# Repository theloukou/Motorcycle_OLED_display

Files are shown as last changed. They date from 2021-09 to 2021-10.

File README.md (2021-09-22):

# Motorcycle information display
ESP32-based Motorcycle Information Display

This is an ESP32 based system, intented for older motorcycles. It is an expansion of the AVR implementation found in the main_avr branch.
It utilizes a small 128x32 OLED diplay module to display motor and ambient temperatures from a set of NTC thermistor/DS18B20, as well as time information through an RTC IC.

New features compared to the Arduino/AVR version are:
* Syncing RTC time via onboard web server
* Uploading new firmware via Wifi, without need to remove system/connect to PC
* Custom PCB to minimize system footprint. Choice between pin-compatible DS1307/PCF8523

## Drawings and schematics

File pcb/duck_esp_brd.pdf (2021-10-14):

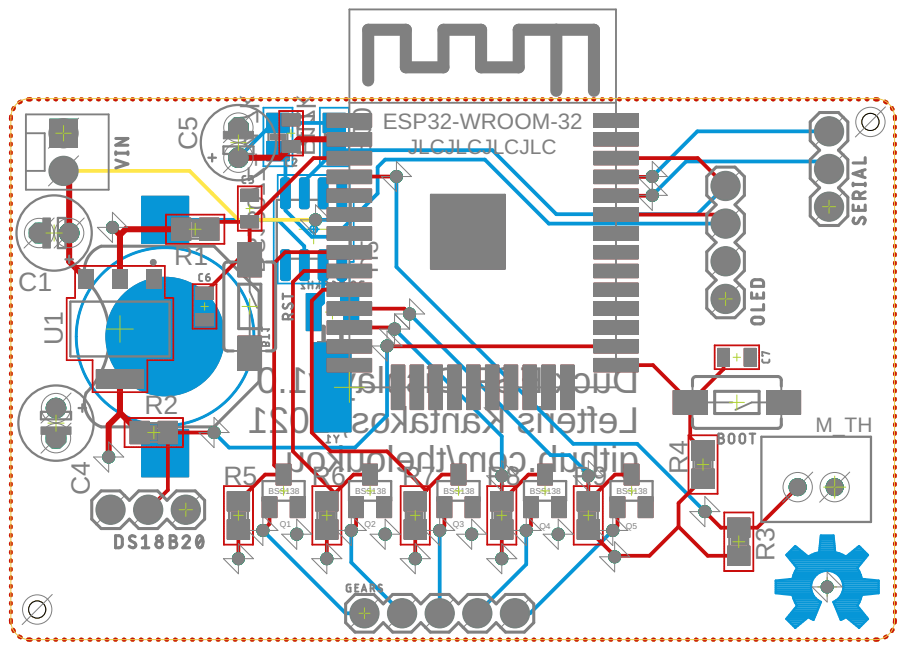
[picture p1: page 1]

DS1307Z+ 4.7k 4.7k 0. 1v yal psi D PSEkcu D 1202, sokat naKsir etf eL uokuol eht/ moc. buhti g U2 R10 R11ESP32-WROOM-32 JLCJLCJLCJLC M_TH R1 R2 R3 U1 R4 C1 C4 C5 Q1 R5 Q2 R6 Q3 R7 Q4 R8 Q5 R9 BSS138 BSS138 BSS138 BSS138 BSS138

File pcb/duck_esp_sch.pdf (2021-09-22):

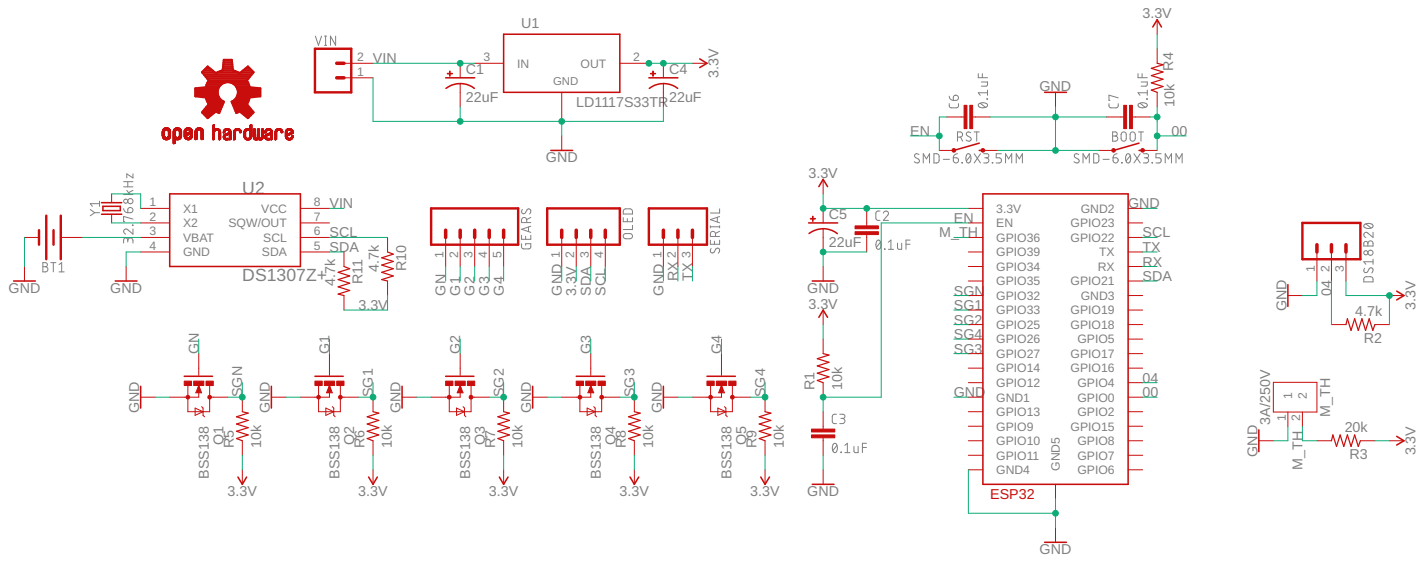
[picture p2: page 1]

10k GND GND 3.3V 3.3V GND GNDLD1117S33TR 3.3V GND G4.7k ND 3.3V 20k GND 3.3V 10k 3.3V 22uF 22uF 22uF BSS138 GND 10k 3.3V BSS138 GND 10k 3.3V BSS138 GND 10k 3.3V BSS138 GND 10k 3.3V BSS138 GND 10k 3.3V DS1307Z+ GND GND 4.7k 4.7k GND4 GPIO11 GPIO10 GPIO9 GPIO13 GND1 GPIO12 GPIO14 GPIO27 GPIO26 GPIO25 GPIO33 GPIO32 GPIO35 GPIO34 GPIO39 GPIO36 EN3.3V GPIO6 GPIO7 GPIO8 GPIO15 GPIO2 GPIO0 GPIO4 GPIO16 GPIO17 GPIO5 GPIO18 GPIO19 GND3 GPIO21 RXTX GPIO22 GPIO23 GND2 GND5 R1 IN 3 OUT 2 GND U1 1234123 123 R2 R3 1 1 2 2M_TH 3A/250V 12 12345 R4 C1 C4 C5 Q1 R5Q2 R6Q3 R7Q4 R8Q5 R9 X1 1 X2 2 VBAT 3 GND 4 SDA 5 SCL 6 SQW/OUT 7 VCC 8 U2 R10 R11 3.3V 3.3V GND GND GND GND SDASDA SDA SCL SCL SCL 00 00 RX RX TX TX M_TH M_TH GN GN G1 G1 G2 G2 G3 G3 G4 G4 EN EN 04 04 VIN VIN SG1 SG1 SG2 SG2 SGN SGN SG4 SG4 SG3 SG3 ESP32

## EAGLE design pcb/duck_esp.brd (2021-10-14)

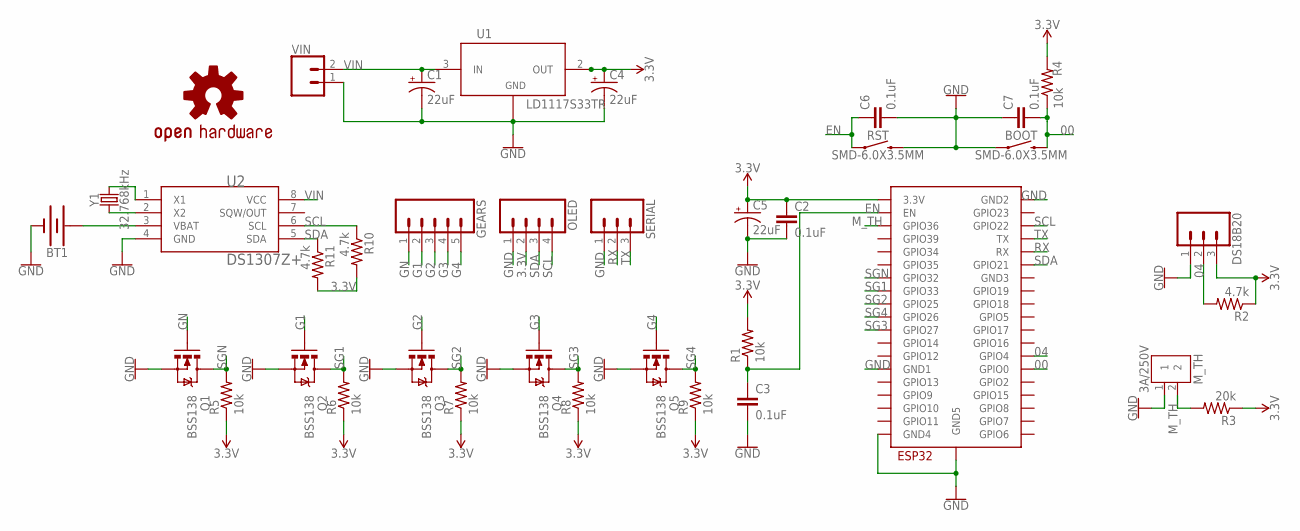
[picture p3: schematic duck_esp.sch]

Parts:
BOOT: SMD-6.0X3.5MM; TACTILE_SWITCH_SMD_6.0X3.5MM
BT1: BATTERY-12MM_SMD; BATTCON_12MM
C1, C4, C5: 22uF; E2-5
C2, C3, C6, C7: 0.1uF; 0805
DS18B20: CONN_03; 1X03
GEARS: CONN_05; 1X05
LOGO1: OSHW-LOGOL-COPPER; OSHW-LOGO-L_COPPER
M_TH: 3A/250V; B2B-XH-A
OLED: CONN_04; 1X04
Q1, Q2, Q3, Q4, Q5: BSS138; SOT23
R1, R4, R5, R6, R7, R8, R9: 10k; R0805
R2, R10, R11: 4.7k; R0805
R3: 20k; R0805
RST: SMD-6.0X3.5MM; TACTILE_SWITCH_SMD_6.0X3.5MM
SERIAL: CONN_03; 1X03
U1: LD1117S33TR; SOT-223
U2: DS1307Z+; SOIC-8N
U$1: ESP32-WROOM
VIN: CONN_02POLAR; MOLEX-1X2
Y1: 32.768kHz; CRYSTAL-SMD-2X6-CYL

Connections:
00: BOOT.2, C7.2, R4.1, U$1.IO0 (GPIO0)
3.3V: C2.1, C4.+, C5.+, DS18B20.3, OLED.2, R1.2, R2.1, R3.1, R4.2, R5.1, R6.1, R7.1, R8.1, R9.1, R10.2, R11.2, U1.2 (OUT), U1.4, U$1.3V3 (3.3V)
04: DS18B20.2, R2.2, U$1.IO4 (GPIO4)
EN: C3.1, C6.1, R1.1, RST.1, U$1.EN
G1: GEARS.2, Q2.1 (G)
G2: GEARS.3, Q3.1 (G)
G3: GEARS.4, Q4.1 (G)
G4: GEARS.5, Q5.1 (G)
GN: GEARS.1, Q1.1 (G)
GND: BOOT.1, BT1.GND (-), C1.-, C2.2, C3.2, C4.-, C5.-, C6.2, C7.1, DS18B20.1, M_TH.1, OLED.1, Q1.2 (S), Q2.2 (S), Q3.2 (S), Q4.2 (S), Q5.2 (S), RST.2, SERIAL.1, U1.1 (ADJ/GND), U2.4 (GND), U$1.GND1, U$1.GND2, U$1.GND4, U$1.GND5, VIN.1
M_TH: M_TH.2, R3.2, U$1.SENSOR_VP (GPIO36)
RX: SERIAL.2, U$1.RX
SCL: OLED.4, R10.1, U2.6 (SCL), U$1.IO22 (GPIO22)
SDA: OLED.3, R11.1, U2.5 (SDA), U$1.IO21 (GPIO21)
SG1: Q2.3 (D), R6.2, U$1.IO33 (GPIO33)
SG2: Q3.3 (D), R7.2, U$1.IO25 (GPIO25)
SG3: Q4.3 (D), R8.2, U$1.IO27 (GPIO27)
SG4: Q5.3 (D), R9.2, U$1.IO26 (GPIO26)
SGN: Q1.3 (D), R5.2, U$1.IO32 (GPIO32)
TX: SERIAL.3, U$1.TX
VBAT: BT1.PWR@1 (+), U2.3 (VBAT)
VIN: C1.+, U1.3 (IN), U2.8 (VCC), VIN.2
X1: U2.1 (X1), Y1.X2 (2)
X2: U2.2 (X2), Y1.X1 (1)

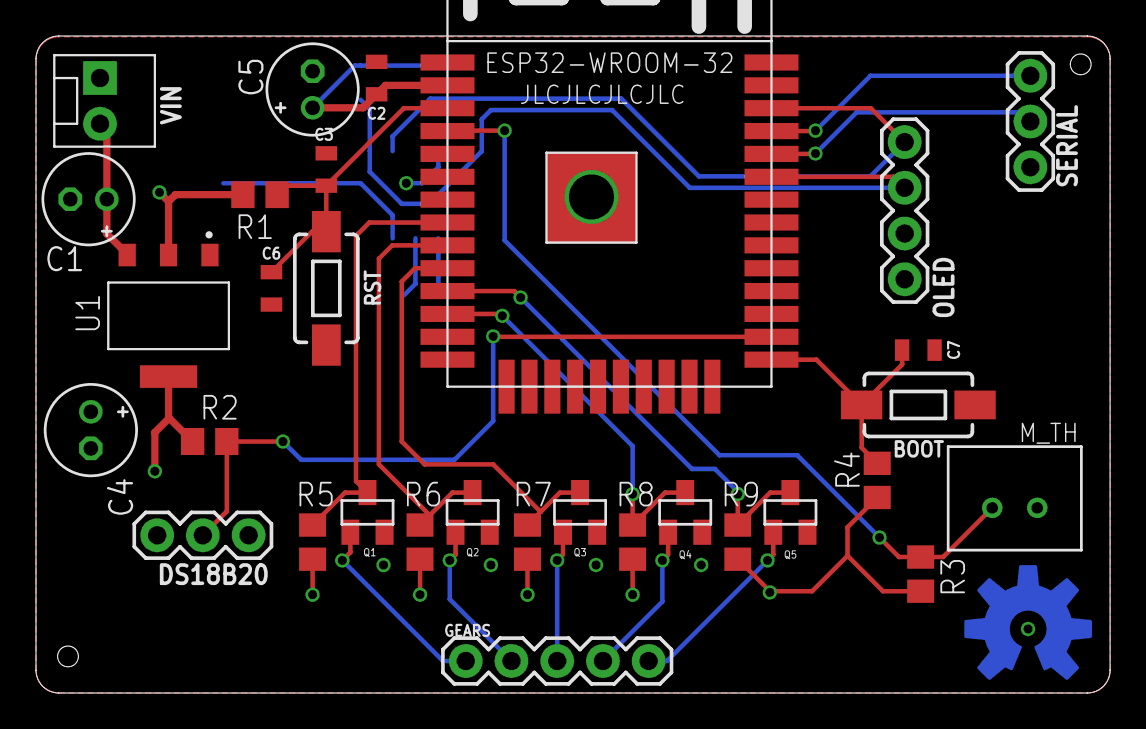
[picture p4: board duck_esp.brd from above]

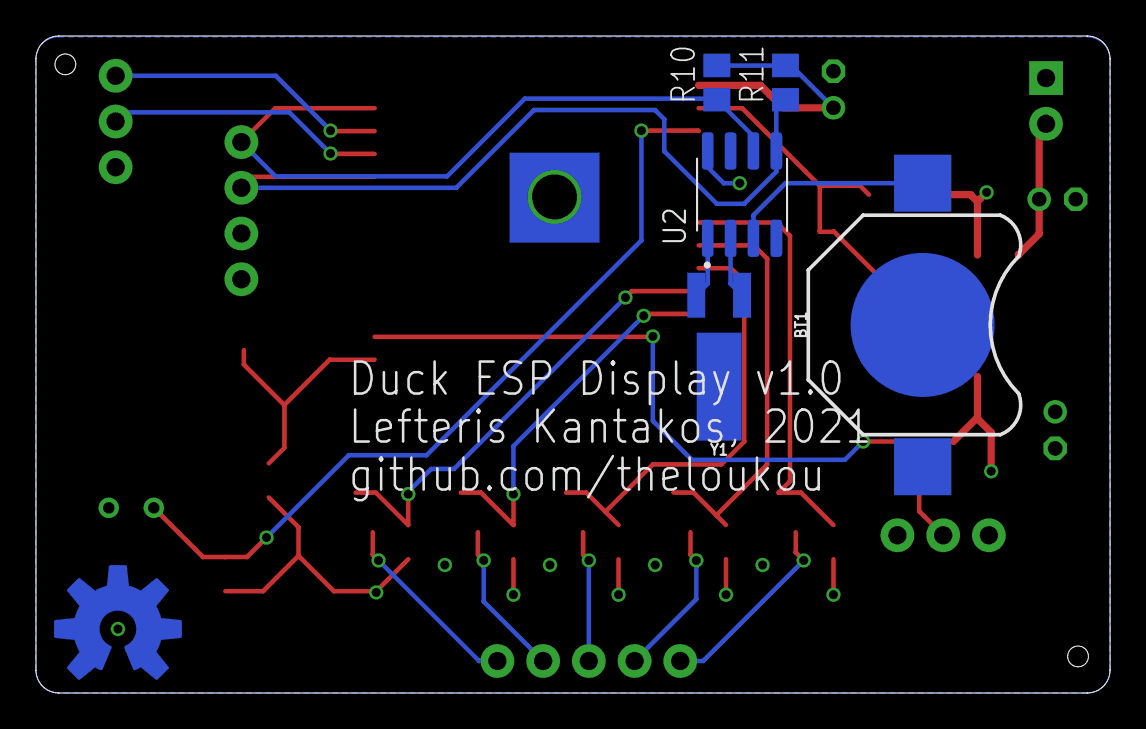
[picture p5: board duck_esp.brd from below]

Board: 4 copper layers, 59.7 x 36.5 mm, 37 parts (6 on the bottom side), 24 nets.

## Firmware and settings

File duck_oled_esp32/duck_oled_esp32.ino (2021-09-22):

#include "definitions.h"
#include <WiFi.h>
#include <ESPAsyncWebServer.h>
#include <AsyncElegantOTA.h>
#include "AsyncJson.h"
#include <ArduinoJson.h>
#include <Wire.h>
#include <Adafruit_GFX.h>
#include <Adafruit_SSD1306.h>
#include <RTClib.h>
#include <OneWire.h>
#include <DallasTemperature.h>
#ifdef CAPTIVE_PORTAL
#include <DNSServer.h>
#endif

const char* ssid = "Duck_WiFi";
const char* password = "problima?";
#ifdef CAPTIVE_PORTAL
DNSServer dnsServer;
#endif
AsyncWebServer server(80);
String header;

RTC_PCF8523 rtc;
DateTime curTime;

OneWire oneWire(ONE_WIRE);
DallasTemperature ds(&oneWire);

Adafruit_SSD1306 display(SCREEN_WIDTH, SCREEN_HEIGHT, &Wire, OLED_RESET);

char gear;
float motorTemp = 60;
float envTemp = 23;
unsigned long lastTemp = 0;
bool dots = false;
String serialStr;

uint16_t samples[NUMSAMPLES];
float res_reading, average = 0;

void setup() {
  btStop(); // Turn off bluetooth
#ifdef SERIAL_DEBUG
  Serial.begin(115200);
  Serial.println("Booting");
#endif
  delay(2000);
  serverSetup();

#ifdef SERIAL_DEBUG
  Serial.println("Starting RTC");
#endif
  rtc.start();

  //reserve memory for variable length serial commands
  serialStr.reserve(40);
  Wire.setClock(I2C_FREQ);

  analogReadResolution(10);

  pinMode(GEAR_N, INPUT_PULLDOWN);
  pinMode(GEAR_1, INPUT_PULLDOWN);
  pinMode(GEAR_2, INPUT_PULLDOWN);
  pinMode(GEAR_3, INPUT_PULLDOWN);
  pinMode(GEAR_4, INPUT_PULLDOWN);

  ds.begin();

#ifdef SERIAL_DEBUG
  Serial.println("Starting display");
#endif
  // SSD1306_SWITCHCAPVCC = generate display voltage from 3.3V internally
  if (!display.begin(SSD1306_SWITCHCAPVCC, 0x3C)) { // Address 0x3C for 128x32
    Serial.println(F("SSD1306 allocation failed"));
    for (;;); // Don't proceed, loop forever
  }

  display.setRotation(2);
  display.clearDisplay();

#ifdef SHOW_LOGOS
  displayBootSeq();
#endif

  display.setTextColor(WHITE, BLACK);
  display.setTextWrap(false);

  curTime = rtc.now();
  displayGearFet();
  diplayTemps();
  displayClock();

#ifdef SERIAL_DEBUG
  Serial.println("Available commands:\n\trtc:YYYY MM DD hh mm ss:end");
  delay(1000);
  Serial.println("Setup done!\n");
#endif
}

void loop() {
  AsyncElegantOTA.loop();
#ifdef CAPTIVE_PORTAL
  dnsServer.processNextRequest();
#endif
#ifdef SERIAL_DEBUG
  if (Serial.available()) serialEvent();
#endif

  if (millis() - lastTemp >= 500) {
    getMotorTemp();
    getAmbientTemp();
    curTime = rtc.now();

    i2cfree();
    display.clearDisplay();
    display.display();
    displayGearFet();
    diplayTemps();
    displayClock();
    lastTemp = millis();
    dots = !dots;

#ifdef SERIAL_DEBUG
    displaySerialOut();
    Serial.printf("Avrg/Th.res/Volts: %f %f %f\r\n", average, res_reading, average / 1024 * 3.3);
#endif

    display.display();
  }
}

void i2cfree() {
  uint16_t halftime = ((1.0 / I2C_FREQ) / 2.0)*1000000; //half period in microseconds
  for (int times = 0; times < 10; times++) {
    digitalWrite(22, LOW);
    delayMicroseconds(halftime);
    digitalWrite(22, HIGH);
    delayMicroseconds(halftime);
  }
}

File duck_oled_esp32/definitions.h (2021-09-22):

//#define SHOW_LOGOS
//#define SERIAL_DEBUG
//#define CAPTIVE_PORTAL

#define ONE_WIRE 4
#define I2C_FREQ 100000

#define SCREEN_WIDTH 128 // OLED display width, in pixels
#define SCREEN_HEIGHT 32 // OLED display height, in pixels
#define OLED_RESET     -1 // Reset pin # (or -1 if sharing Arduino reset pin)

#define GEAR_N 25
#define GEAR_1 26
#define GEAR_2 27
#define GEAR_3 32
#define GEAR_4 33

#define NUMSAMPLES 5
#define MOTOR_THERM 36   //VP pin
#define MOTOR_NOMINAL 100000
#define MOTOR_TEMP_NOMINAL 25
#define MOTOR_B 3950
#define MOTOR_S_RES 20000

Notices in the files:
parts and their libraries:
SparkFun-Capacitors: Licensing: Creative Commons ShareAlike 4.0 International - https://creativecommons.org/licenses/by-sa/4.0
